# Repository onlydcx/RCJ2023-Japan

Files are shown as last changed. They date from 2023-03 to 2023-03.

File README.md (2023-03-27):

## RCJ2023ジャパン用

全てのデータ(ハードウェア、ソフトウェア、回路図、基板図)載ってます。

## HardWareフォルダ
- Attacker.f3z → Fusion360で作成
- 基板データフォルダ → KiCAD6で開いてください

## SoftWareフォルダ
Python以外はVsCodeのPlatformIOで開発。ターゲットはTeensy4.1
- src/main.cpp → メインソース。回り込みとドリブラー制御
- lib/〇〇/〇〇.h 〇〇.cpp → 各モジュールごとのクラス
- OpenMV.py → OpenMV上のMicroPythonで開発。

## Posterフォルダ
プレゼンテーションシート

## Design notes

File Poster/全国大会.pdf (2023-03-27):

Kollagen 〇〇 〇 … アタッカー機
〇〇 〇〇 … キーパー機
〇〇 〇〇〇 … 電子回路

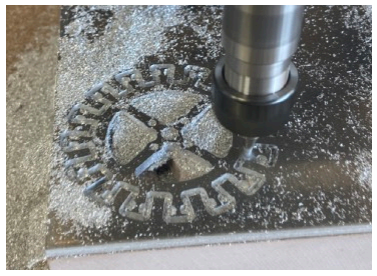
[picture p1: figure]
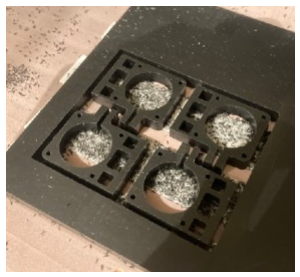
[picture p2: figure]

バッテリー Li-Fe 9.9V

モーター制御 DRV8874

マイコン | Teensy4.1
モーター | XBD 1640
ドリブラー | C2822 BLDC
コンデンサ | 50V 4700uF
ライン素子 | NJL7302F3

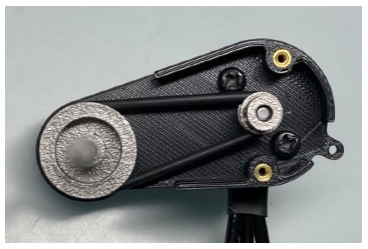
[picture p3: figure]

カメラ | OpenMV H7+

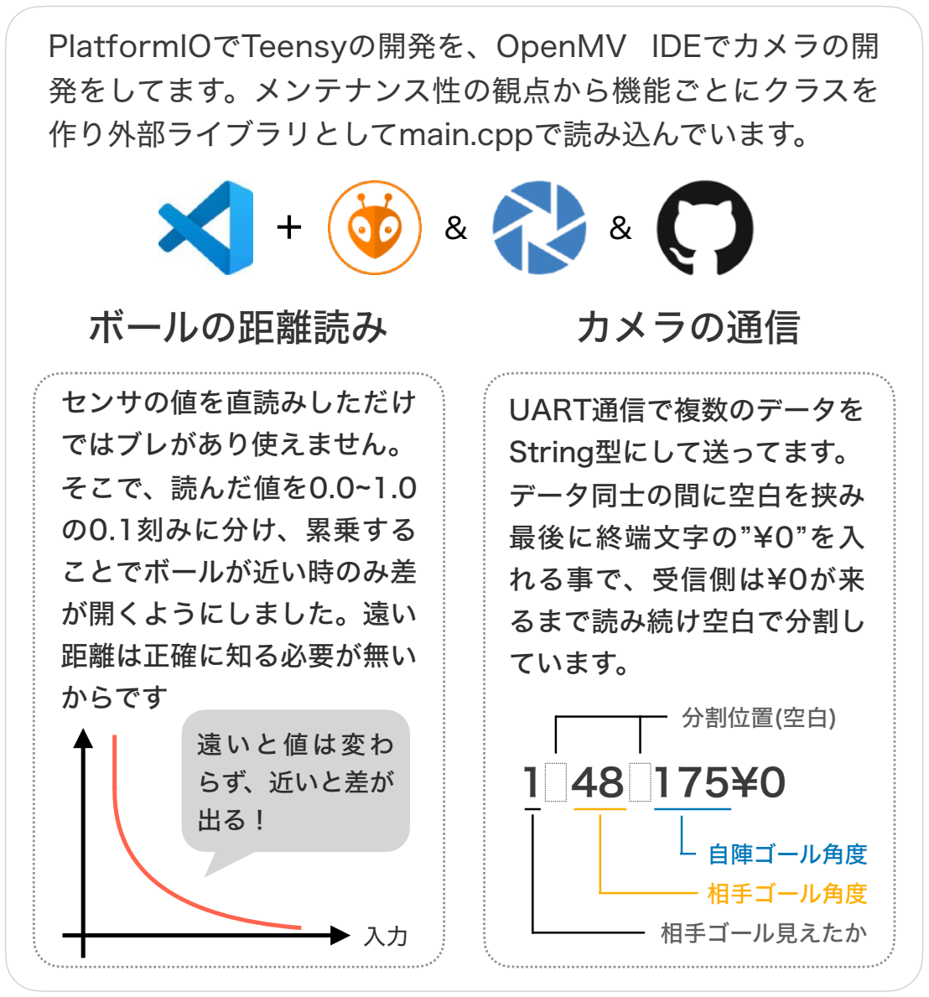
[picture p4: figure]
ボールの距離読み; カメラの通信; UART通信で複数のデータを; String型にして送ってます。; データ同士の間に空白を挟み; 最後に終端文字の”¥0”を入; れる事で、受信側は¥0が来; るまで読み続け空白で分割し; ています。; 自陣ゴール角度; 相手ゴール角度; 相手ゴール見えたか; 分割位置(空白); センサの値を直読みしただけ; ではブレがあり使えません。; そこで、読んだ値を0.0~1.0; の0.1刻みに分け、累乗する; ことでボールが近い時のみ差; が開くようにしました。遠い; 距離は正確に知る必要が無い; からです; 遠いと値は変わ らず、近いと差が; PlatformIOでTeensyの開発を、OpenMV IDEでカメラの開; 発をしてます。メンテナンス性の観点から機能ごとにクラスを 作り外部ライブラリとしてmain.cppで読み込んでいます。
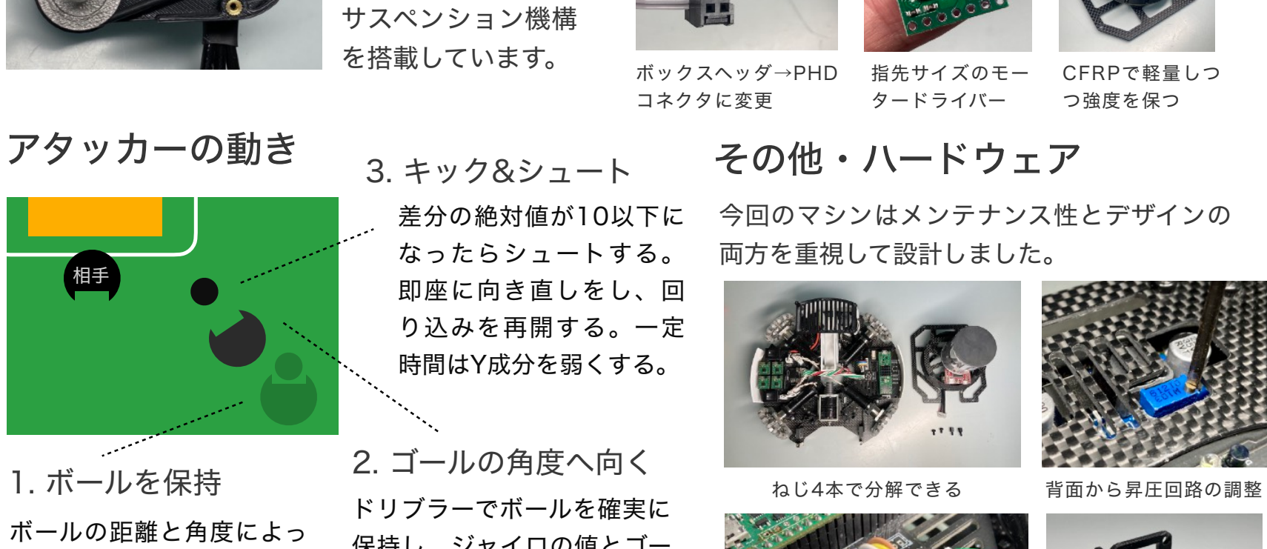
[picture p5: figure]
サスペンション機構 を搭載しています。; ボックスヘッダ→PHD コネクタに変更; 指先サイズのモー タードライバー; CFRPで軽量しつ つ強度を保つ; 1. ボールを保持; 2. ゴールの角度へ向く; 3. キック&シュート アタッカーの動き; ボールの距離と角度によっ; ドリブラーでボールを確実に; 差分の絶対値が10以下に; なったらシュートする。; 即座に向き直しをし、回; り込みを再開する。一定; 時間はY成分を弱くする。; ねじ4本で分解できる; その他・ハードウェア; 今回のマシンはメンテナンス性とデザインの; 両方を重視して設計しました。; 背面から昇圧回路の調整

Supported By

From Toda, Saitama

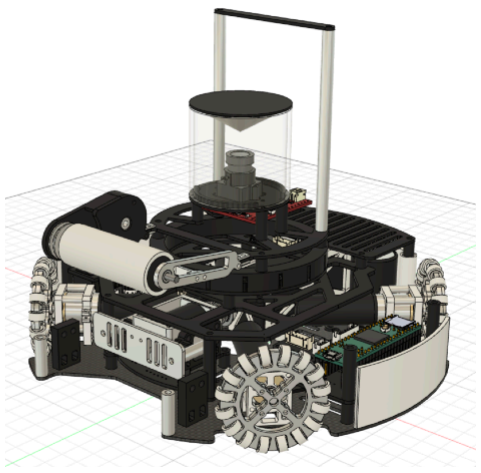
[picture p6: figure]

## SoftWare

# WSL014

## 格安モーターへ挑戦

MaxonRE16と同等性能で半額程度の中華コアレ
スモーターを使用しています。 磁気漏れが酷いので
近くにマイコンを置かな
いように設計しました。
100kHzのPWMによる
LAP方式で制御してます

## 工作施設の活用

CNCなどの高価な機材が家になくても工作施設
を使えば安く手軽に加工ができる！

## ドリブラー

トルクを出す為にBLDCを約3:1に減速し、また
ボールが近くなったら低速回転させて スムーズに
保持ができます。
プーリーはJLCPCB
のメタルプリントで
作成し、バネによる

## 小型軽量化

モータードライバやコネクタを小さいものに変更
したり、基板枚数を減らし軽量化を図りました

オープンソース

設計図、ソフトウェアや

回路図はGitHubから👉

て場合分けし、連続的な値
をとる回り込み関数により
滑らかに回り込む。

保持し、ジャイロの値とゴー
ルの角度の差分の絶対値が
10以下になるまで前進しな
がら回る。この時カメラの値
は更新しない。

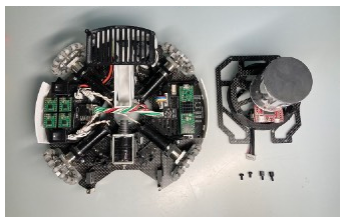
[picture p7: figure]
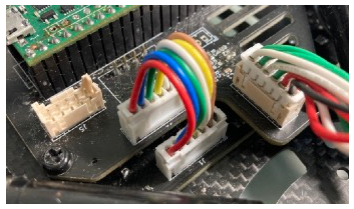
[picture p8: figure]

マルチプレクサを使った配線の削減 一体成形パーツの使用

開発費用 … 13万円
開発期間 … 2ヶ月

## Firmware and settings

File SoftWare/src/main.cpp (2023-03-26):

#include "Arduino.h"
#include <Wire.h>
#include "Motor.h"
#include "IMU.h"
#include "Line.h"
#include "Ball.h"
#include "Cam.h"
#include "Servo.h"

#define dribbrer 37

Servo esc;
Motor motor;
Line line;
Cam cam;

unsigned long lastKick = 0;
bool isNear = (BallStr > 450) && ((BallAngle < 15) || (BallAngle > 345));

bool iscatch() {
   return (analogRead(A13) < 150);
}

int rey() {
   float distance = float(dis), angle = float(goal);
   angle = 90 - angle;
   angle *= (PI / 180);
   int y = distance * sin(angle);
   return y;
}

bool isBlue = 0;

void drribler_init() {
   pinMode(dribbrer,OUTPUT);
   esc.attach(dribbrer);
   esc.writeMicroseconds(2000);
   delay(2000);
   esc.writeMicroseconds(1000);
   delay(2000);
}

void dribble(int mode) {
   int pulse[3] = {1000, 1400, 2000};
   esc.writeMicroseconds(pulse[mode]);
}

int gy180() {
   int __gy = GyroGet();
   if(__gy > 180) __gy -= 360;
   return __gy;
}

bool kick() {
   if((millis() - lastKick) > 150) {
      digitalWrite(20,HIGH);
      delay(150);
      digitalWrite(20,LOW);
      lastKick = millis();
      return true;
   }
   else return false;
}

void setup() {
   Serial.begin(9600);
   Serial8.begin(19200);
   Wire.begin();
   GyroInit();
   pinMode(20,OUTPUT);
   BallInit();
   drribler_init();
   speed = 140;
   // line.ThUpdate();
   // while(1) {}
}

void loop() {
   IRUpDate();
   line.check();
   cam.update();

   if(isOnLine) {
      motor.run(avoidAngle);
      delay(20);
   }
   else {
      if(isNoBall) {
         motor.stop();
      }
      else {
         int dirPlus = 0;
         if (BallAngle <= 40) {
            dirPlus = BallAngle ;
         }
         else if (BallAngle >= 320) {
            dirPlus = (360 - BallAngle);
         }
         else {
            dirPlus = 50;
         }

         int toMove = 180;
         if(isNear) dribble(1);
         else dribble(0);

         if(!isNoGoal) {
            while(iscatch() && !isOnLine) {
               line.check();
               cam.update();

               if(rey() > 105) {
                  dribble(2);
                  speed = 220;
                  motor.run(goal);
               }
               else {
                  speed = 150;
                  if((goal < 35) || (goal > 325)) { // 目の前
                     dribble(1);
                     kick();
                  }
                  else if((goal < 50) || (goal > 310)) { // 狙える位置
                     dribble(2);
                     cam.update(); 
                     motor.run(goal);
                     // if(goal <= 180){
                     //    motor.run(goal + 30);
                     // }else{
                     //    motor.run(goal - 30);
                     // }
                  }
                  else {
                     // if(((goal >= 45) && (goal < 90)) || ((goal <= 300) && (goal > 270))) { // 狙うには急すぎ
                        dribble(2);
                        int time = millis();
                        while(((millis() - time) < 1500)) {
                           cam.update();
                           motor.run(180);
                           if(((goal < 45) || (goal > 300)) || !iscatch()) {
                              motor.stop();
                              // delay(100);
                              break;
                           }
                        }
                     // }
                  }
               }

            }
         }



         if (BallStr < 300) {
            toMove = BallAngle;
         }
         else if (BallStr > 400) {
            if (BallAngle <= 5 || BallAngle >= 355) {
               toMove = BallAngle;
            }
            else {
               if (BallAngle <= 180) {
                  toMove = BallAngle + dirPlus * 1.1;
               }
               else {
                  toMove = BallAngle - dirPlus * 1.1;
               }
            }
         }
         else {
            if (BallAngle <= 180) {
               toMove = BallAngle + dirPlus;
            } 
            else {
               toMove = BallAngle - dirPlus;
            }
         }
         motor.run(toMove);
      }
   }
}

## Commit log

2023-03-17 ファイルをアップロード
    [IR-Unit.kicad_pcb, IR-Unit.kicad_sch, Line.kicad_pcb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]
2023-03-23 ドリブラー関数を追加
2023-03-25 更新 @10:05
2023-03-25 2試合目のやつ
2023-03-25 第3試合
2023-03-26 第7試合
2023-03-26 エキシビションマッチのやつ
2023-03-27 写真を追加
2023-03-27 色々変更
2023-03-27 ポスターを追加
2023-03-27 不要部分を削除
2023-03-27 Git関連
